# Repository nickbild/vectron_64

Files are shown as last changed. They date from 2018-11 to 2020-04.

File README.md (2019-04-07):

<p align="center">
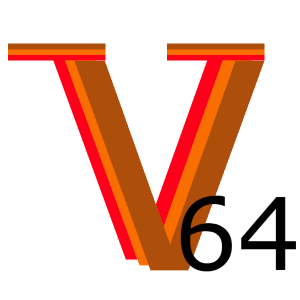
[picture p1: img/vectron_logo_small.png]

</p>

# Vectron 64

Custom-built general purpose, programmable, [6502](https://en.wikipedia.org/wiki/MOS_Technology_6502)-based computer and operating system.

## Specs

* [6502 CPU](https://en.wikipedia.org/wiki/MOS_Technology_6502) clocked at 1 Mhz.
* 32KB RAM
* 32KB EEPROM
  - Programmable via custom microcontroller based platform.
* 16x2 character LCD display.
* PS/2 keyboard support.
* Built with 7400 series logic contemporary with the original 6502 CPU.

## Schematics

[Fritzing Schematics](https://raw.githubusercontent.com/nickbild/6502_os/master/schematics/6502_computer.fzz)

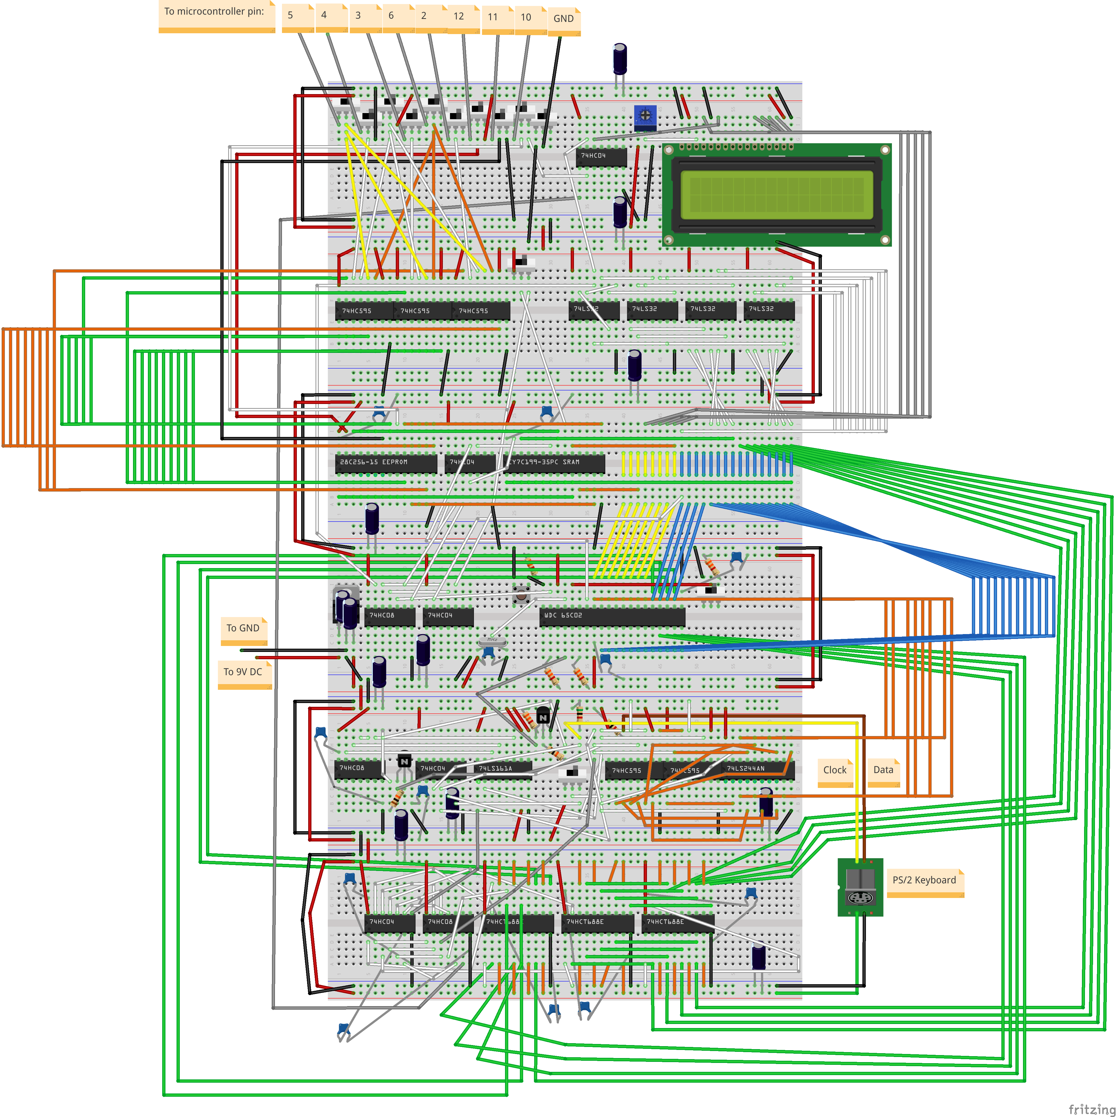
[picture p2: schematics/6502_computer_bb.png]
Schematics Image


## Images

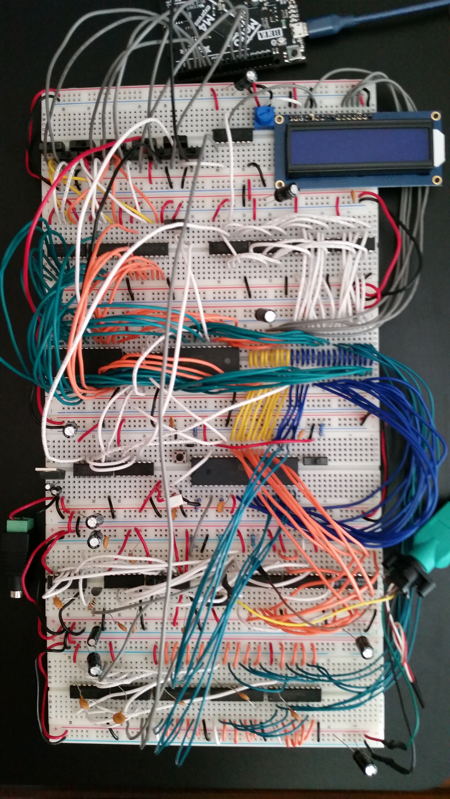
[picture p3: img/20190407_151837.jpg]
6502 Computer


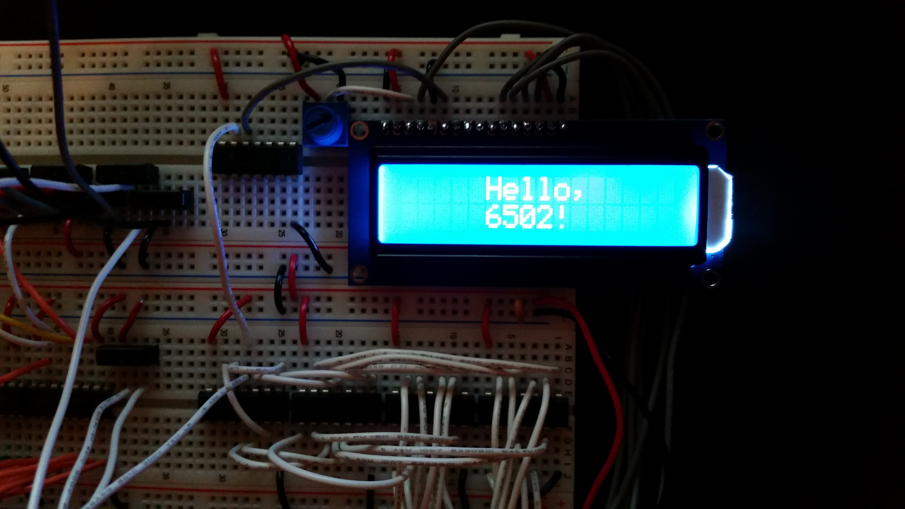
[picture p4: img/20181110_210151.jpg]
LCD


## Operation

All slide switches must be switched to the right for normal operating mode.  Connect a 9V DC power supply and the computer will begin running the program stored in ROM.

To program ROM, slide all switches to the left.  Connect a microcontroller dev board (Arduino-like) per wiring guidance in the schematics.  Code to perform the programming routine is available in my [EEPROM Burner](https://github.com/nickbild/eeprom_burner) repository.

A small utility, `hex.py`, has been provided to generate the calls to the `write` function that are required (in [EEPROM Burner](https://github.com/nickbild/eeprom_burner)) to transfer your binary to the ROM.  Create a text file named `hex.txt` with hex codes, one byte per line, then run:

```
python hex.py
```

The included ROM image, [6502.asm](https://raw.githubusercontent.com/nickbild/6502_os/master/6502.asm), will capture keyboard input and display it on the LCD screen.  This serves as a good template from which to build more complex applications.

## Reserved Memory

| Address | Use |
| --- | --- |
| $0000 | LCD enable |
| $0001 | Unused -- read it to disable any IC (except RAM). |
| $0002 | Current LCD cursor position. |
| $0003 | Flag to indicate if next scan code should be skipped. |
| $0100-$01FF | 6502 stack |
| $7FBE-$7FBF | Temporary location for LCD data manipulation. |
| $7FC0-$7FFF | Data to write to LCD. Each character (16 x 2 lines) is represented by 2 consecutive bytes (4-bit mode). Most sig. 4 bits are for LCD data. Least sig. 4 bits - only bit 3 used (tied to RS pin). |
| $FFF8 | Clock keyboard shift register and enable line buffer. |
| $FFF9 | Reset binary counter (counts bits received from PS/2 keyboard packets). |
| $FFFA | NMI IRQ Vector |
| $FFFB | NMI IRQ Vector |
| $FFFC | Reset Vector - Stores start address of this ROM. |
| $FFFD | Reset Vector |
| $FFFE | IRQ Vector - Keyboard ISR address. |
| $FFFF | IRQ Vector |

## Bill of Materials

| Quantity | Part Type | Properties |
| --- | --- | --- |
| 11	| Ceramic Capacitor	| package 200 mil [THT, multilayer]; voltage 6.3V; capacitance 0.1µF |
| 9	| Electrolytic Capacitor | package 100 mil [THT, electrolytic]; voltage 6.3V; capacitance 220µF |
| 1	| Electrolytic Capacitor | package 100 mil [THT, electrolytic]; voltage 6.3V; capacitance 47µF |
| 2	| Electrolytic Capacitor | package 100 mil [THT, electrolytic]; voltage 6.3V; capacitance 22µF |
| 1	| Ceramic Capacitor	package | 200 mil [THT, multilayer]; voltage 6.3V; capacitance 0.01µF |
| 3	| 74HC08 Logic AND Gate	| variant Variant 1; pins 14; chip label 74HC08; editable pin labels false; package DIP (Dual Inline) [THT]; pin spacing 300mil; part # 74HC08 |
| 3	| 74HCT688E	| pins 20; hole size 1.0mm,0.508mm; chip label 74HCT688E; true; package DIP (Dual Inline) [THT]; pin spacing 300mil |
| 1	| 74LS161A	| pins 16; hole size 1.0mm,0.508mm; chip label 74LS161A; true; package DIP (Dual Inline) [THT]; pin spacing 300mil |
| 1	| 74LS244AN	| pins 20; hole size 1.0mm,0.508mm; chip label 74LS244AN; true; package DIP (Dual Inline) [THT]; pin spacing 300mil |
| 1	| WDC 65C02	| pins 40; hole size 1.0mm,0.508mm; chip label WDC 65C02; true; package DIP (Dual Inline) [THT]; pin spacing 300mil |
| 5	| 74HC04 | pins 14; hole size 1.0mm,0.508mm; chip label 74HC04; true; package DIP (Dual Inline) [THT]; pin spacing 300mil |
| 1	| Voltage Regulator	| variant sink; chip 78005; package to220-igo; voltage 5V |
| 1	| 28C256-15 EEPROM | pins 28; hole size 1.0mm,0.508mm; chip label 28C256-15 EEPROM; true; package DIP (Dual Inline) [THT]; pin spacing 300mil |
| 1	| CY7C199-35PC SRAM | pins 28; hole size 1.0mm,0.508mm; chip label CY7C199-35PC SRAM; true; package DIP (Dual Inline) [THT]; pin spacing 300mil |
| 4	| 74LS32 | pins 14; hole size 1.0mm,0.508mm; chip label 74LS32; true; package DIP (Dual Inline) [THT]; pin spacing 300mil |
| 1	| LCD screen | pins 16; type Character |
| 2	| NPN-Transistor | package TO92 [THT]; type NPN (EBC) |
| 2	| 10kΩ Resistor | tolerance ±5%; resistance 10kΩ; package 2512 [SMD] |
| 2	| 5kΩ Resistor | tolerance ±5%; resistance 5kΩ; package 2512 [SMD] |
| 5	| 3.3kΩ Resistor | tolerance ±5%; resistance 3.3kΩ; package 2512 [SMD] |
| 1	| Pushbutton | package [THT] |
| 5	| 74HC595 | package DIP16 [THT]; type 74HC595 |
| 13	| SWITCH_SPDT | package kps-1290 |
| 1	| POT | variant 100k_3362u; package 3362u |
| 1	| mini DIN 6 Connector | variant pth; package mini-din6; connector Mini-DIN6 |
| 1	| Crystal | frequency 1 MHz; package THT; type crystal; pin spacing 5.08mm |

## About the Author

[Nick A. Bild, MS](https://nickbild79.firebaseapp.com/#!/)

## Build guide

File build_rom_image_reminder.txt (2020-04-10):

- Assemble to source:
dasm 6502.asm -l6502.list

- Use text editor to copy/manipulate listing to get sequential list of bytes (1 per line).
  - Copy addresses starting from $8000. Do not include IRQ or Reset vectors.
  - Name it "hex.txt".

- Prepare microcontroller code:
python hex.py

- Copy writes into EEPROM burner Arduino code (https://github.com/nickbild/eeprom_burner).
  - Make sure to set program start address (in $FFFC-$FFFD) and, if needed, IRQ (in $FFFE-$FFFF).
    - These addresses are found at the end of the listing.

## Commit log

2019-03-25 Schematics in process.
    [6502_computer.fzz]
2019-03-26 Update schematics.
    [6502_computer.fzz]
2019-04-01 Save progress on schematics.
    [6502_computer.fzz]
2019-04-02 Place all components.
    [6502_computer.fzz]
2019-04-02 Begin wiring.
    [6502_computer.fzz]
2019-04-02 Continue adding wiring.
    [6502_computer.fzz]
2019-04-03 Continue wiring.
    [6502_computer.fzz]
2019-04-07 Finish wiring!
    [6502_computer.fzz]
2019-04-07 Wire up ROM programmer.
    [6502_computer.fzz]
2019-04-07 Fix bill of materials table.
